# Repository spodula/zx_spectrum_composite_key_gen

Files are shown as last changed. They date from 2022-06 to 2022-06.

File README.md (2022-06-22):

# zx_spectrum_composite_key_gen
zx Spectrum composite key generator PCB. 

This PCB goes in parallel with the normal keyboard tails and allows composite keys to be wired to their own seperate keys with a seperate header for the cursor keys. 

Bugs: 
Left diodes are backwards to the rest. Silk screen is correct. Be careful assembling

Corrected bugs:
U4 is the wrong way around
Most of the symbol shift chars are not linked to to symbol shift. Whoops.

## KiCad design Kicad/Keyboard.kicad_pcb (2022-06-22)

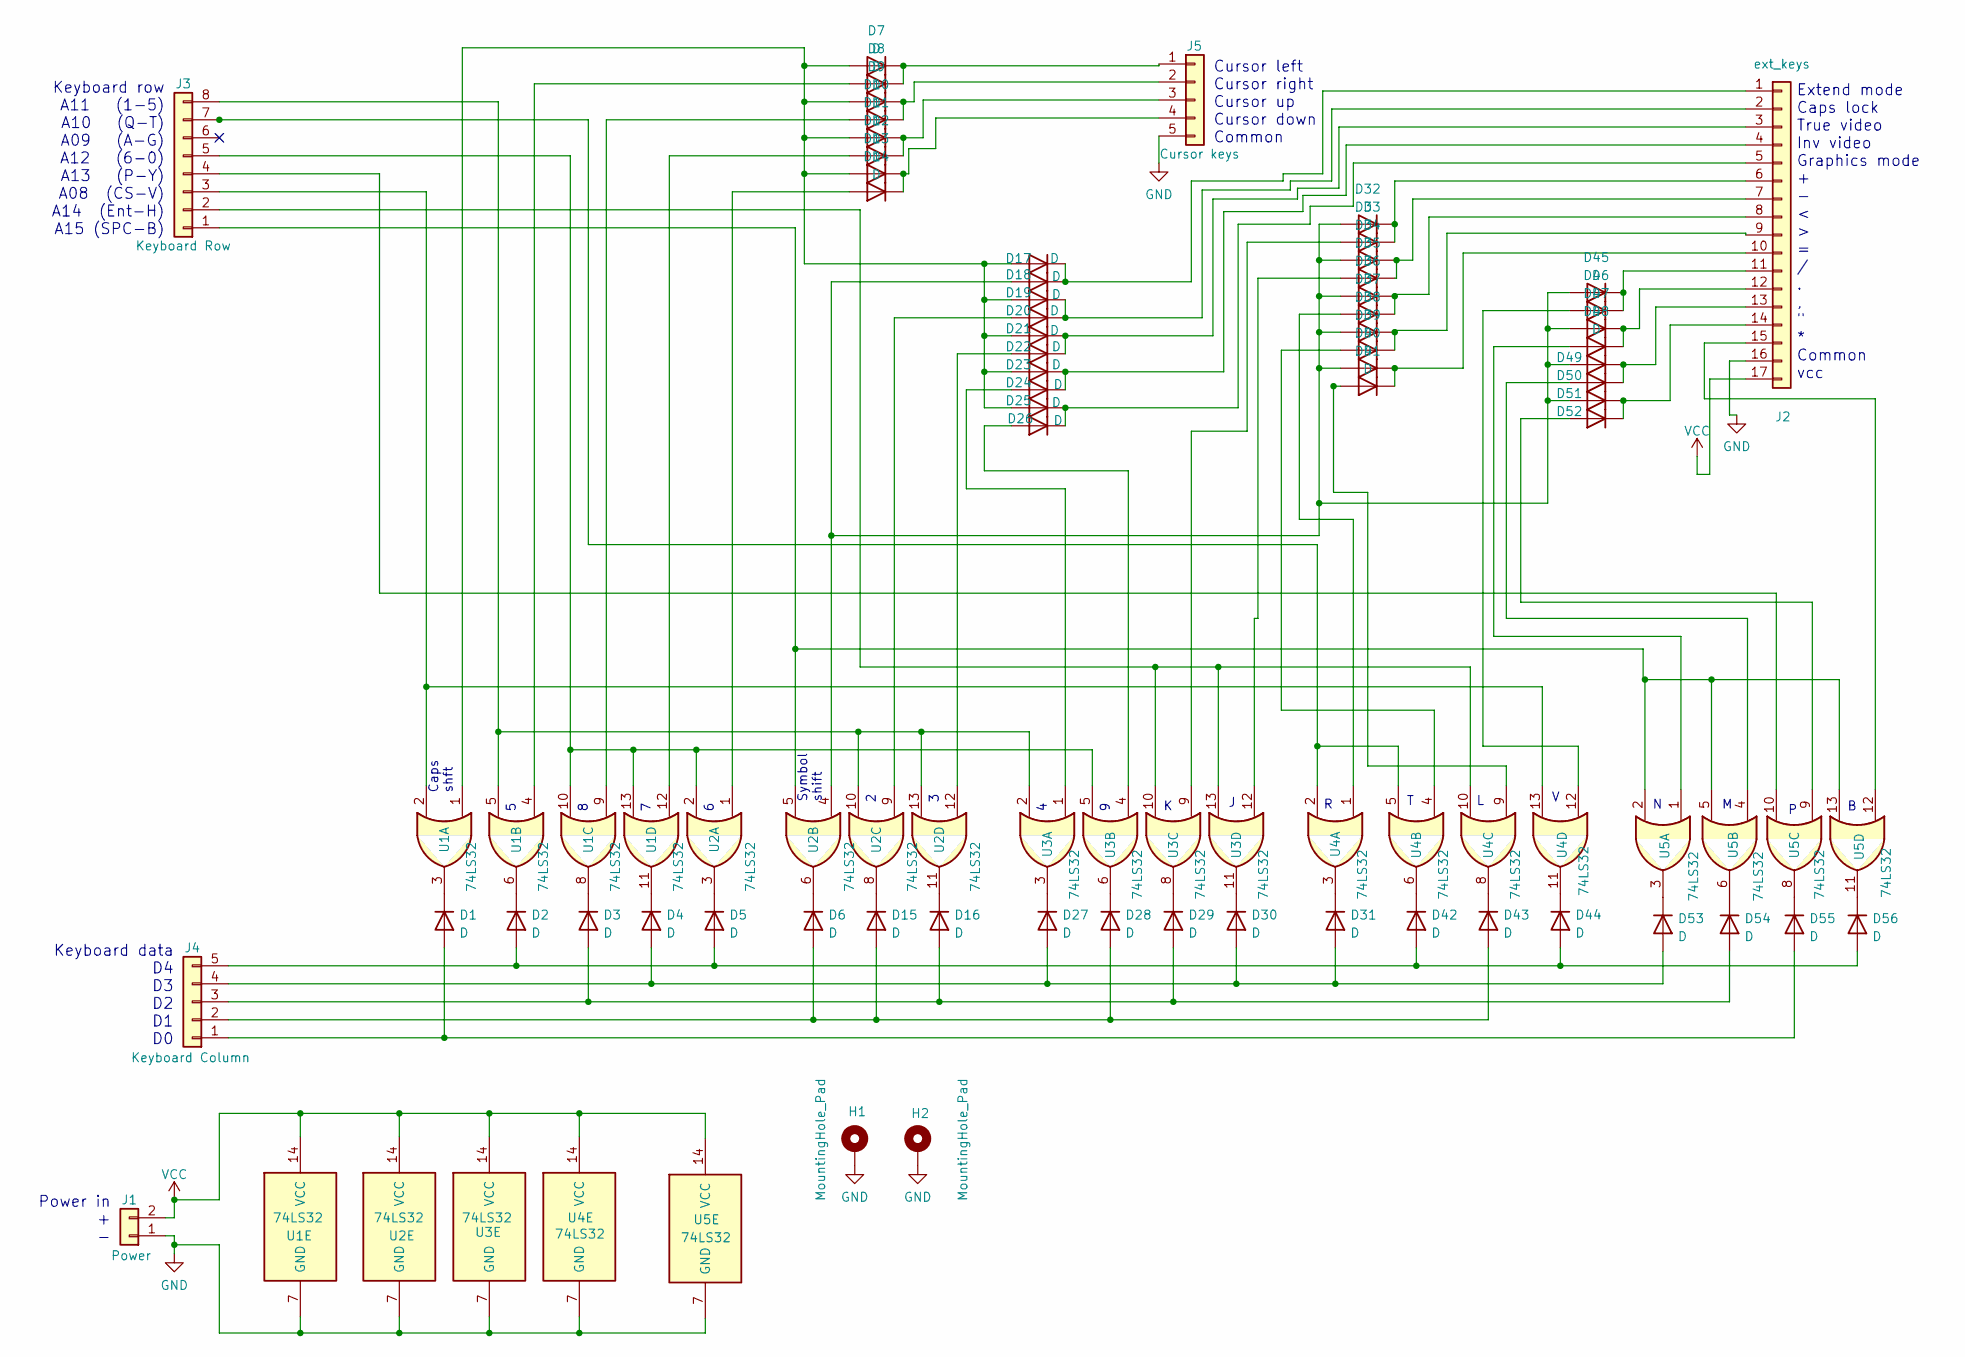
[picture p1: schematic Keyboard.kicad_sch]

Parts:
D1, D2, D3, D4, D5, D6, D7, D8, D9, D10, D11, D12, D13, D14, D15, D16, D17, D18, D19, D20, D21, D22, D23, D24, D25, D26, D27, D28, D29, D30, D31, D32, D33, D34, D35, D36, D37, D38, D39, D40, D41, D42, D43, D44, D45, D46, D47, D48, D49, D50, D51, D52, D53, D54, D55, D56: D; D_A-405_P7.62mm_Horizontal
H1, H2: MountingHole_Pad; MountingHole_3.5mm_Pad
J1: Power; PinSocket_1x02_P2.54mm_Horizontal
J2: ext_keys; PinSocket_1x17_P2.54mm_Horizontal
J3: Keyboard Row; PinSocket_1x08_P2.54mm_Horizontal
J4: Keyboard Column; PinSocket_1x05_P2.54mm_Horizontal
J5: Cursor keys; PinSocket_1x05_P2.54mm_Horizontal
U1, U2, U3, U4, U5: 74LS32; DIP-14_W7.62mm_LongPads

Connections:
GND: H1.1, H2.1, J1.1, J2.16, J5.5, U1.7 (GND), U2.7 (GND), U3.7 (GND), U4.7 (GND), U5.7 (GND)
unnamed: D1.1 (K), U1.3
unnamed: D1.2 (A), D55.2 (A), J4.1
unnamed: D2.1 (K), U1.6
unnamed: D2.2 (A), D5.2 (A), D42.2 (A), D44.2 (A), D56.2 (A), J4.5
unnamed: D3.1 (K), U1.8
unnamed: D4.1 (K), U1.11
unnamed: D5.1 (K), U2.3
unnamed: D6.1 (K), U2.6
unnamed: D7.1 (K), D8.1 (K), J5.1
unnamed: D8.2 (A), U1.4
unnamed: D9.1 (K), D10.1 (K), J5.2
unnamed: D10.2 (A), U1.9
unnamed: D11.1 (K), D12.1 (K), J5.3
unnamed: D7.2 (A), D9.2 (A), D11.2 (A), D13.2 (A), D17.2 (A), D19.2 (A), D21.2 (A), D23.2 (A), D25.2 (A), U1.1
unnamed: D12.2 (A), U1.12
unnamed: D13.1 (K), D14.1 (K), J5.4
unnamed: D14.2 (A), U2.1
unnamed: D15.1 (K), U2.8
unnamed: D6.2 (A), D15.2 (A), D28.2 (A), D43.2 (A), J4.2
unnamed: D16.1 (K), U2.11
unnamed: D3.2 (A), D16.2 (A), D29.2 (A), D54.2 (A), J4.3
unnamed: D17.1 (K), D18.1 (K), J2.1
unnamed: D18.2 (A), D32.2 (A), D34.2 (A), D36.2 (A), D38.2 (A), D40.2 (A), D45.2 (A), D47.2 (A), D49.2 (A), D51.2 (A), U2.4
unnamed: D19.1 (K), D20.1 (K), J2.2
unnamed: D20.2 (A), U2.9
unnamed: D21.1 (K), D22.1 (K), J2.3
unnamed: D22.2 (A), U2.12
unnamed: D23.1 (K), D24.1 (K), J2.4
unnamed: D24.2 (A), U3.1
unnamed: D25.1 (K), D26.1 (K), J2.5
unnamed: D26.2 (A), U3.4
unnamed: D27.1 (K), U3.3
unnamed: D4.2 (A), D27.2 (A), D30.2 (A), D31.2 (A), D53.2 (A), J4.4
unnamed: D28.1 (K), U3.6
unnamed: D29.1 (K), U3.8
unnamed: D30.1 (K), U3.11
unnamed: D31.1 (K), U4.3
unnamed: D32.1 (K), D33.1 (K), J2.6
unnamed: D33.2 (A), U3.9
unnamed: D34.1 (K), D35.1 (K), J2.7
unnamed: D35.2 (A), U3.12
unnamed: D36.1 (K), D37.1 (K), J2.8
unnamed: D37.2 (A), U4.1
unnamed: D38.1 (K), D39.1 (K), J2.9
unnamed: D39.2 (A), U4.4
unnamed: D40.1 (K), D41.1 (K), J2.10
unnamed: D41.2 (A), U4.9
unnamed: D42.1 (K), U4.6
unnamed: D43.1 (K), U4.8
unnamed: D44.1 (K), U4.11
unnamed: D45.1 (K), D46.1 (K), J2.11
unnamed: D46.2 (A), U4.12
unnamed: D47.1 (K), D48.1 (K), J2.12
unnamed: D48.2 (A), U5.1
unnamed: D49.1 (K), D50.1 (K), J2.13
unnamed: D50.2 (A), U5.4
unnamed: D51.1 (K), D52.1 (K), J2.14
unnamed: D52.2 (A), U5.9
unnamed: D53.1 (K), U5.3
unnamed: D54.1 (K), U5.6
unnamed: D55.1 (K), U5.8
unnamed: D56.1 (K), U5.11
unnamed: J2.15, U5.12
unnamed: J3.1, U2.5, U5.2, U5.5, U5.13
unnamed: J3.2, U3.10, U3.13, U4.10
unnamed: J3.3, U1.2, U4.13
unnamed: J3.4, U5.10
unnamed: J3.5, U1.10, U1.13, U2.2, U3.5
unnamed: J3.7, U4.2, U4.5
unnamed: J3.8, U1.5, U2.10, U2.13, U3.2
VCC: J1.2, J2.17, U1.14 (VCC), U2.14 (VCC), U3.14 (VCC), U4.14 (VCC), U5.14 (VCC)

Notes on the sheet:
Power in + -
Caps shft
Cursor left Cursor right Cursor up Cursor down Common
Extend mode Caps lock True video Inv video Graphics mode + - < > = / . , " * Common vcc
Symbol shift
Keyboard data D4 D3 D2 D1 D0
Keyboard row A11 (1-5) A10 (Q-T) A09 (A-G) A12 (6-0) A13 (P-Y) A08 (CS-V) A14 (Ent-H) A15 (SPC-B)

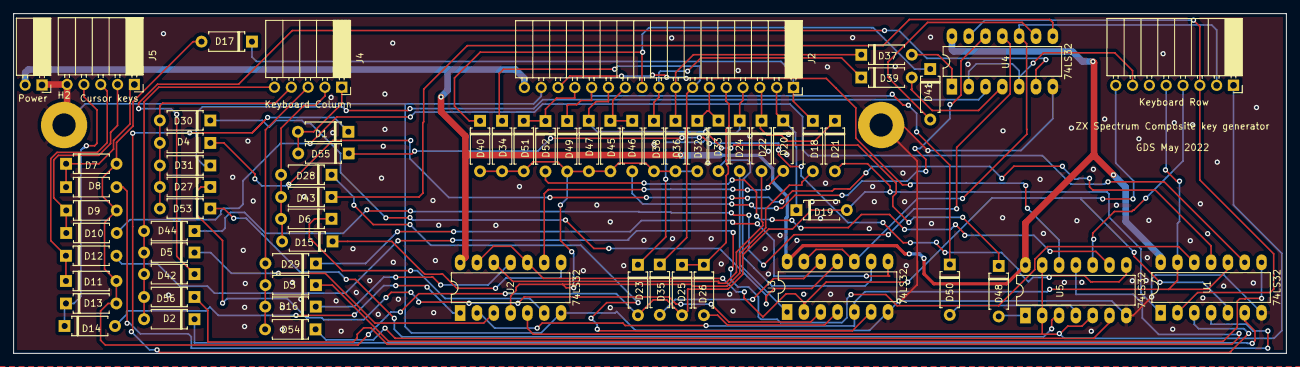
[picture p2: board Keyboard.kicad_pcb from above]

Board: 2 copper layers, 192.2 x 51.3 mm, 68 parts (0 on the bottom side), 72 nets.
